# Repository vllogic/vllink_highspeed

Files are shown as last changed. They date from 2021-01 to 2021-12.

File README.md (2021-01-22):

# Vllink HighSpeed

## 简介

Vllink Highspeed是一款中低成本高性能调试器。相比Lite版，支持USB2.0高速、更好的IO时序优化、更好的CPU速度，预计JTAG/SWD接口对目标芯片SRAM速度可以达到MB/S的级别，媲美当前千元级别调试器。

## 硬件

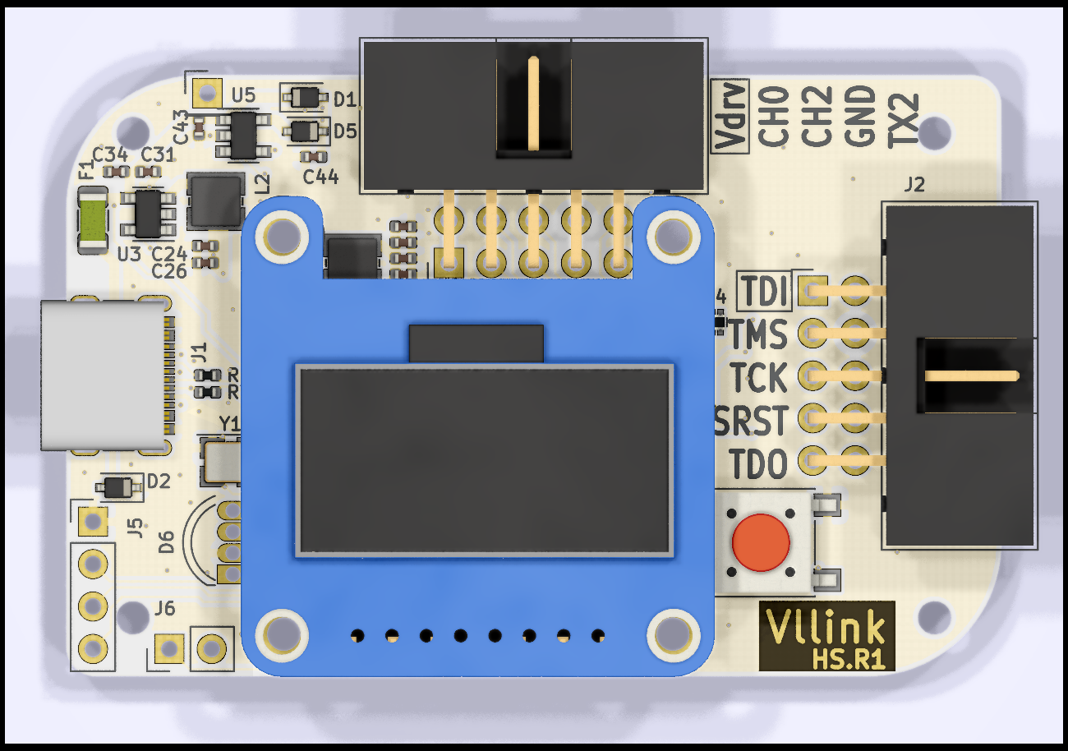
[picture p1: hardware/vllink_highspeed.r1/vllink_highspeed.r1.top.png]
top

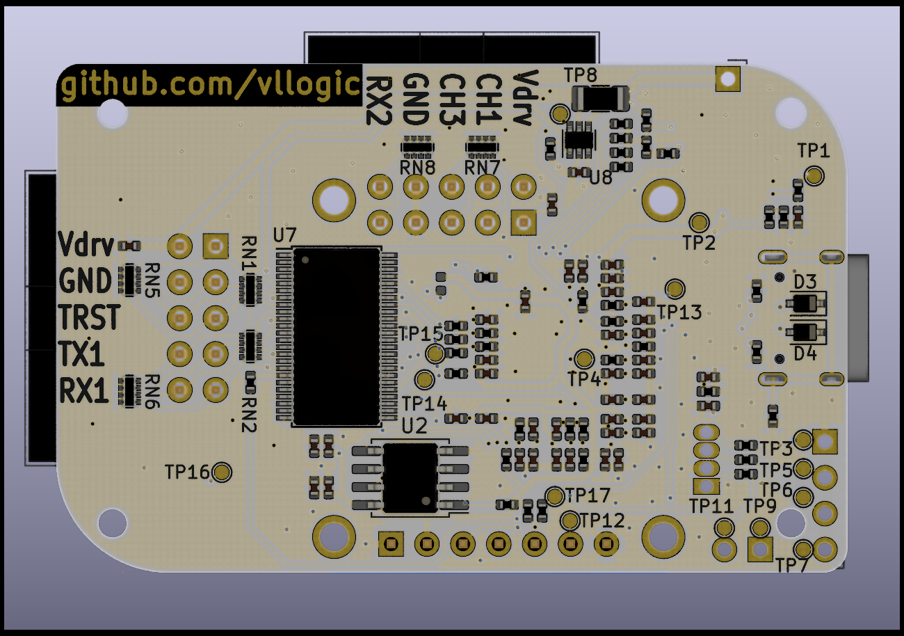
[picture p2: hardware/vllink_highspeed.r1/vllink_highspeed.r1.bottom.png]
bottom

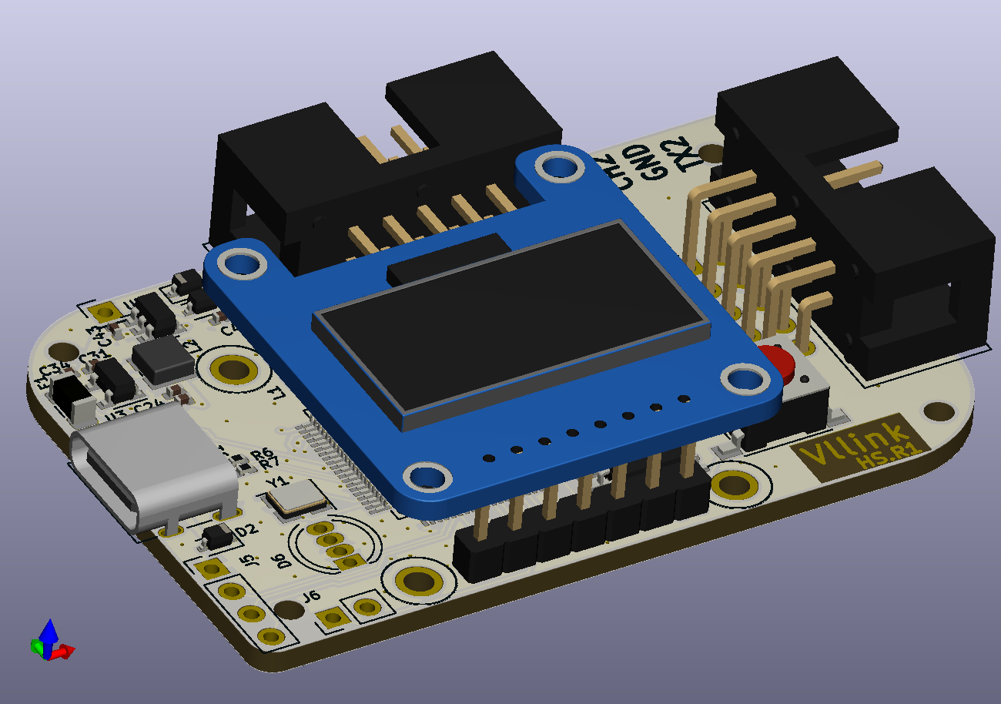
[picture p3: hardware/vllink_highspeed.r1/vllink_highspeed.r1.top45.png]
top45


## 功能
* JTAG/SWD接口(TDI,TMS,TCK,SRST,TDO,TRST)
* 2路独立串口(TX1,RX1,TX2,RX2)，1路共用串口(TDO,SRST)
* 4通道逻辑分析输入口(CH0,CH1,CH2,CH3)
* 具有电平转换电路，同时支持外部参考电源与内部数字可调电源1.5V至4.75V(Vdrv)
* 使用内部电源对外供电时，支持电流测量(Vdrv)
* OLED_12864(全彩LED可选)
* 远超同等价格级别硬件的Code/Data空间

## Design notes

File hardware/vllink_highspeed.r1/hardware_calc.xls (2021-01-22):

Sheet: LDO_OUT1
Vref | R1 | R2.1 | R2.1_X | R2.1_R | R2.2 | R2.2_X | R2.2_R | R2.3 | R2.3_X | R2.3_R | R2.4 | R2.4_X | R2.4_R | R2.5 | R2.5_X | R2.5_R | R2(12) | R2(34) | R2(1234) | R2(12345) | Vout
1.207 | 100 | 412 | 1 | 412 | 60.4 | 10000 | 604000 | 121 | 10000 | 1210000 | 243 | 10000 | 2430000 | 475 | 10000 | 4750000 | 411.7191585 | 807774.7253 | 411.509414 | 411.4737665 | 1.500335833
1.207 | 100 | 412 | 1 | 412 | 60.4 | 10000 | 604000 | 121 | 10000 | 1210000 | 243 | 10000 | 2430000 | 475 | 1 | 475 | 411.7191585 | 807774.7253 | 411.509414 | 220.4905764 | 1.754415685
1.207 | 100 | 412 | 1 | 412 | 60.4 | 10000 | 604000 | 121 | 10000 | 1210000 | 243 | 1 | 243 | 475 | 10000 | 4750000 | 411.7191585 | 242.951209 | 152.7908888 | 152.7859742 | 1.996993981
1.207 | 100 | 412 | 1 | 412 | 60.4 | 10000 | 604000 | 121 | 10000 | 1210000 | 243 | 1 | 243 | 475 | 1 | 475 | 411.7191585 | 242.951209 | 152.7908888 | 115.604851 | 2.251073834
1.207 | 100 | 412 | 1 | 412 | 60.4 | 10000 | 604000 | 121 | 1 | 121 | 243 | 10000 | 2430000 | 475 | 10000 | 4750000 | 411.7191585 | 120.9939752 | 93.51287682 | 93.51103587 | 2.497756742
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

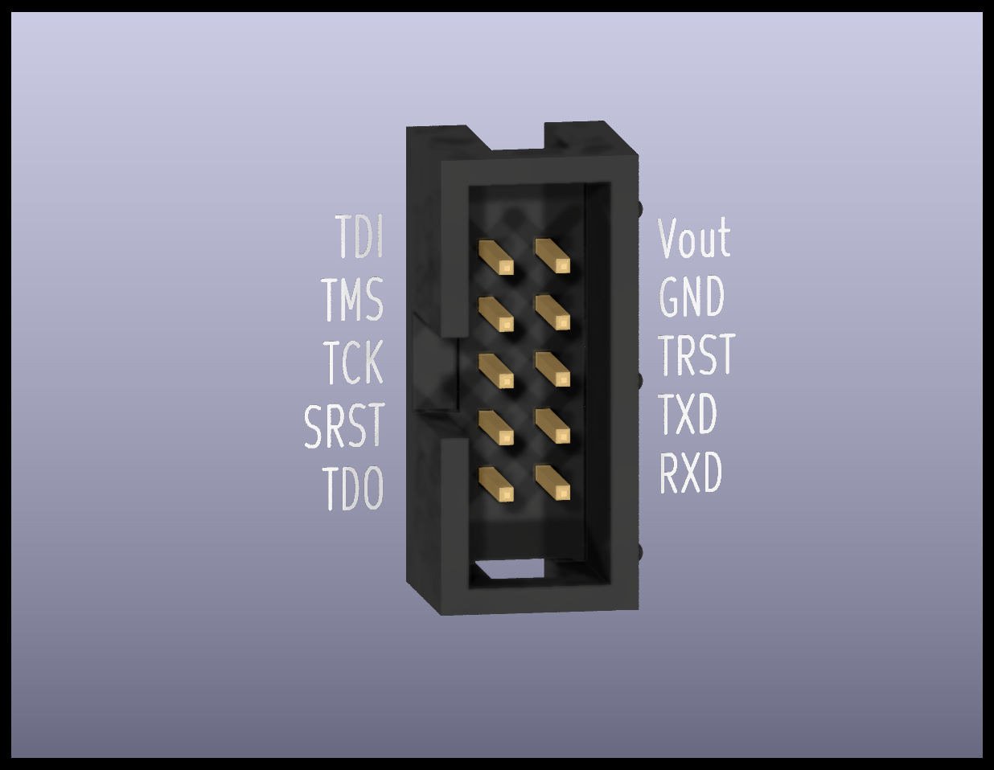
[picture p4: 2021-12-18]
hardware/vllink_basic/hardware.version1/vllink_basic.20211123.interface.png

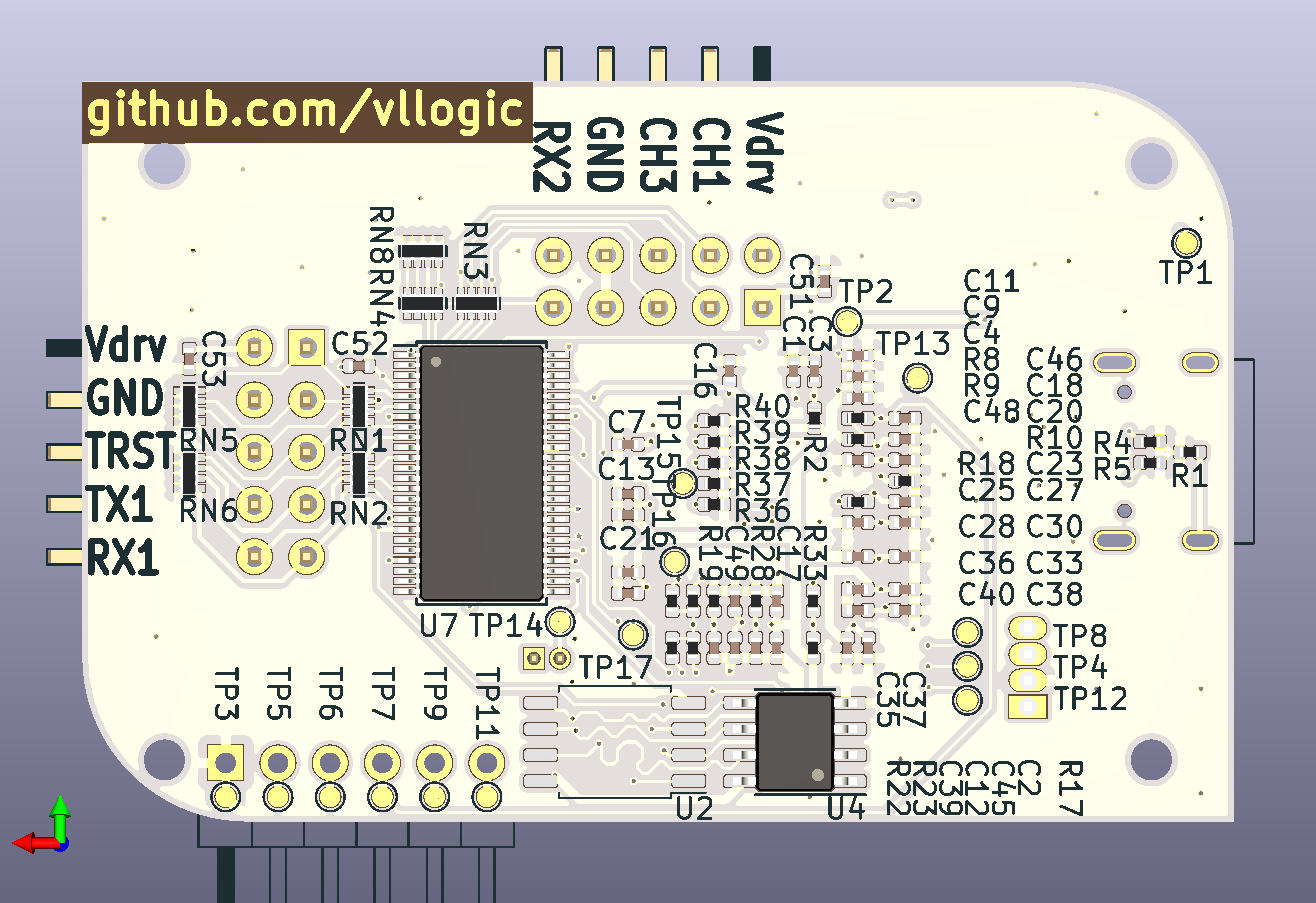
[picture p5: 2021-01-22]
hardware/vllink_highspeed.r0/vllink_highspeed.r0.bottom.png

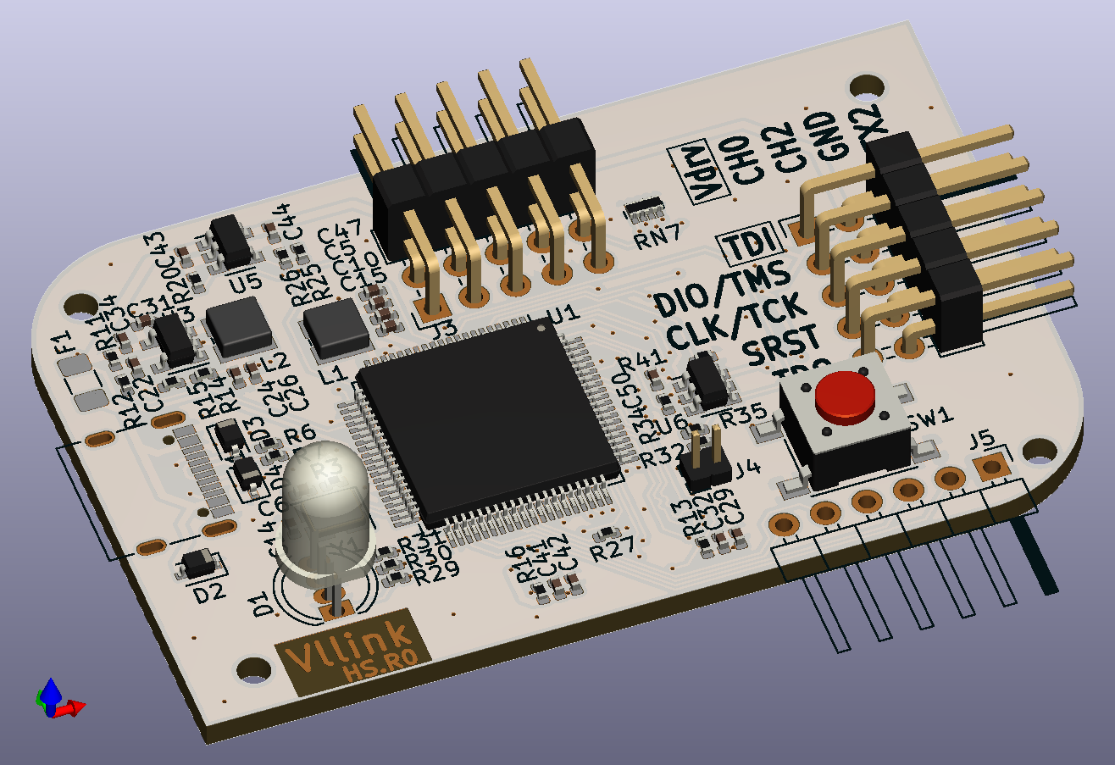
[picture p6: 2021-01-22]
hardware/vllink_highspeed.r0/vllink_highspeed.r0.top45.png

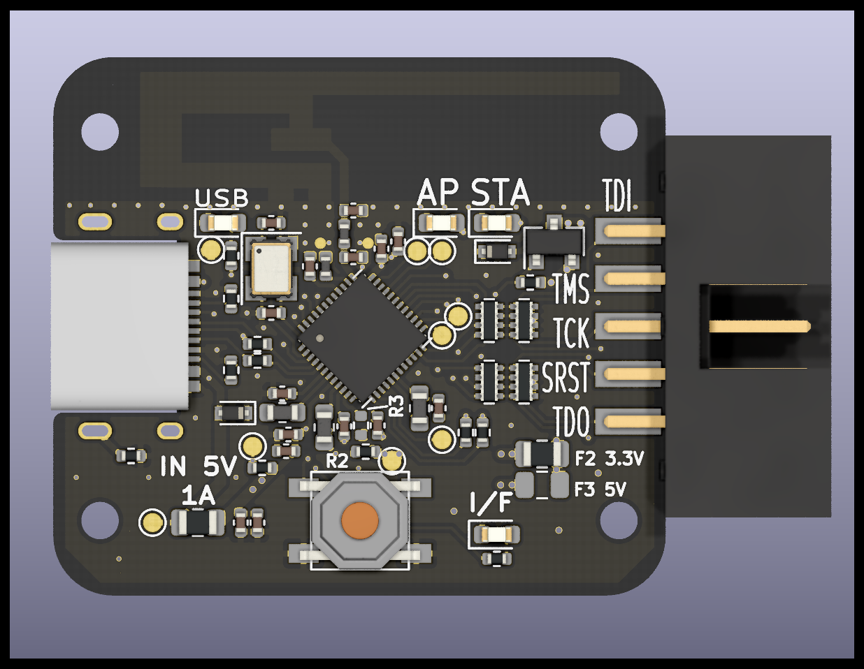
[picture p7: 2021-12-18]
hardware/vllink_basic/hardware.version1/vllink_basic.20211123.top.png

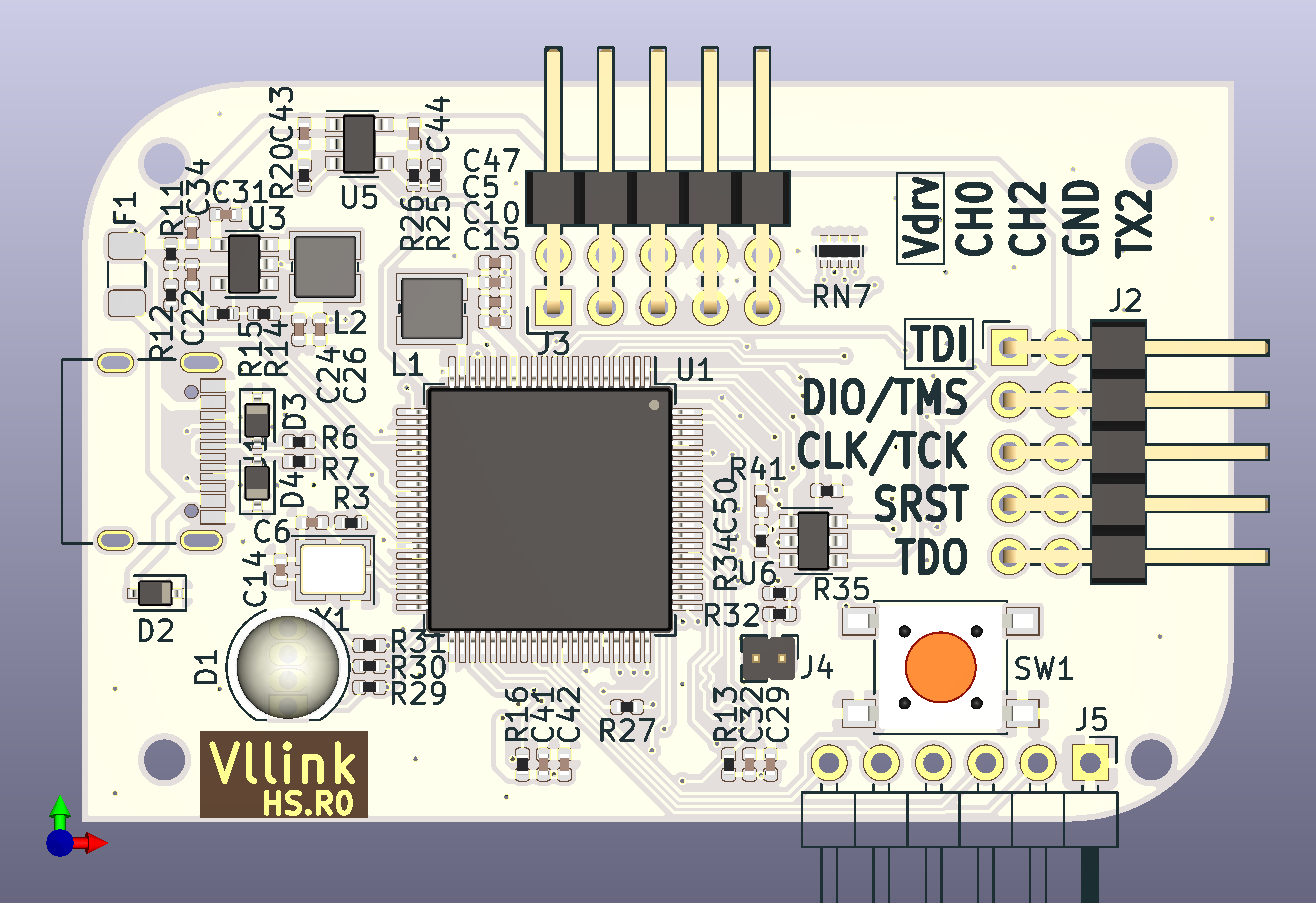
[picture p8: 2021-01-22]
hardware/vllink_highspeed.r0/vllink_highspeed.r0.top.png

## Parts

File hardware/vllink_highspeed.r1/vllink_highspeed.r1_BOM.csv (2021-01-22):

Comment | Description | Designator | Footprint | LibRef | Pins | Quantity | PartNumber | url
0.22uF | desc | C26,C15, | C_0402_1005Metric | libref | 2 | 2
10uF | desc | C43,C44,C47,C34,C24,C10,C5, | C_0402_1005Metric | libref | 2 | 7
0.1uF | desc | C52,C50,C31, | C_0402_1005Metric | libref | 2 | 3
BAT60A, NC | desc | D1, | D_SOD-323 | libref | 2 | 1
LESD3Z5.0C | desc | D2, | D_SOD-323 | libref | 2 | 1
BAT60A | desc | D5, | D_SOD-323 | libref | 2 | 1
Polyfuse,2A | desc | F1, | Fuse_1206_3216Metric | libref | 2 | 1
4.7uH | desc | L1,L2, | L_Wuerth_MAPI-3012 | libref | 2 | 2
4.7k | desc | R32, | R_0402_1005Metric | libref | 2 | 1
22 | desc | R7,R6, | R_0402_1005Metric | libref | 2 | 2
220 | desc | RN4,RN3, | R_Array_Concave_4x0402 | libref | 8 | 2
SW_Push | desc | SW1, | SW_SPST_PTS645 | libref | 4 | 1
MIMXRT1011 | desc | U1, | LQFP-80_12x12mm_P0.5mm | libref | 80 | 1
ETA3486 | desc | U3, | SOT-23-5 | libref | 5 | 1
W25Q128JVS | desc | U4, | SOIC-8_P1.27mm_Common | libref | 8 | 1
SGM2019-ADJ | desc | U5, | SOT-23-5 | libref | 5 | 1
74LVC1T45GW | desc | U6, | SOT-363_SC-70-6 | libref | 6 | 1
24M, 12pF | desc | Y1, | Crystal_SMD_3225-4Pin_3.2x2.5mm | libref | 4 | 1
12pF | desc | C14,C6, | C_0402_1005Metric | libref | 2 | 2
0.22uF | desc | C38,C35,C33,C30,C22,C20,C18,C12,C11,C7,C4,C3,C1, | C_0402_1005Metric | libref | 2 | 13
1uF | desc | C42,C37,C32,C23, | C_0402_1005Metric | libref | 2 | 4
4.7uF | desc | C49,C48,C40,C36,C28,C21,C19,C17,C9, | C_0402_1005Metric | libref | 2 | 9
10uF | desc | C53,C51,C25, | C_0402_1005Metric | libref | 2 | 3
0.1uF | desc | C54,C46,C41,C45,C39,C29,C27,C16,C13,C8,C2, | C_0402_1005Metric | libref | 2 | 11
LESD3Z5.0C | desc | D4,D3, | D_SOD-323 | libref | 2 | 2
0,NC | desc | R12, | R_0402_1005Metric | libref | 2 | 1
47k | desc | R13,R30,R41,R40,R39,R38,R37,R36,R35,R16,R20,R33, | R_0402_1005Metric | libref | 2 | 12
274k,1% | desc | R14, | R_0402_1005Metric | libref | 2 | 1
30k | desc | R2, | R_0402_1005Metric | libref | 2 | 1
121k,1% | desc | R22, | R_0402_1005Metric | libref | 2 | 1
243k,1% | desc | R23, | R_0402_1005Metric | libref | 2 | 1
475k,1% | desc | R24, | R_0402_1005Metric | libref | 2 | 1
100k,1% | desc | R25,R11, | R_0402_1005Metric | libref | 2 | 2
412k,1% | desc | R26, | R_0402_1005Metric | libref | 2 | 1
60.4k,1% | desc | R28,R27,R21,R19,R18,R15, | R_0402_1005Metric | libref | 2 | 6
0.05, 1%, 1206 | desc | R29, | R_1206_3216Metric | libref | 2 | 1
2.2M | desc | R3, | R_0402_1005Metric | libref | 2 | 1
47k,NC | desc | R34,R17, | R_0402_1005Metric | libref | 2 | 2
4.7k | desc | R43,R42,R31, | R_0402_1005Metric | libref | 2 | 3
0 | desc | R44,R10,R9,R1, | R_0402_1005Metric | libref | 2 | 4
5.1k | desc | R5,R4, | R_0402_1005Metric | libref | 2 | 2
10k | desc | R8, | R_0402_1005Metric | libref | 2 | 1
220 | desc | RN2,RN1, | R_Array_Concave_4x0402 | libref | 8 | 2
220k | desc | RN8,RN7,RN6,RN5, | R_Array_Concave_4x0402 | libref | 8 | 4
TestPoint | desc | TP17,TP16,TP15,TP13,TP12,TP11,TP9,TP8,TP7,TP6,TP5,TP4,TP3,TP2,TP1,TP14, | TestPoint_Pad_D1.0mm | libref | 1 | 16
LY68L6400 | desc | U2, | SOIC-8_P1.27mm_Common | libref | 8 | 1
74ALVC164245DGG | desc | U7, | TSSOP-48_6.1x12.5mm_P0.5mm | libref | 48 | 1
TP199A2/TP181A2 | desc | U8, | SOT-363_SC-70-6 | libref | 6 | 1
Through Hole Items
LED_RCGB | desc | D6, | LED_D5.0mm-4_RGB | libref | 4 | 1
USB_C_Receptacle_USB2.0 | desc | J1, | USB_C_Receptacle_Palconn_UTC16-G | libref | 22 | 1
JTAG/SWD/UART0 | desc | J2, | IDC-Header_2x05_P2.54mm_Horizontal | libref | 10 | 1
LogicIN/UART1 | desc | J3, | IDC-Header_2x05_P2.54mm_Horizontal | libref | 10 | 1
Mode | desc | J4, | PinHeader_1x02_P1.27mm_Vertical | libref | 2 | 1
SWD | desc | J5, | PinHeader_1x04_P2.54mm_Vertical | libref | 4 | 1
UART | desc | J6, | PinHeader_1x02_P2.54mm_Vertical | libref | 2 | 1
Vdrive_I | desc | J7, | PinHeader_1x01_P2.54mm_Vertical | libref | 1 | 1
OLED_12864 | desc | OLED1, | OLED_12864 | libref | 11 | 1

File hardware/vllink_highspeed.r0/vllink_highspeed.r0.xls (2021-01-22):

Reference | Quantity | Value | Footprint | 单价 | 合计
C28 C40 C9 C36 C19 C21 C17 C49 C48 | 9 | 4.7uF | Capacitor_SMD:C_0402_1005Metric | 0.01 | 0.09
C35 C20 C30 C38 C3 C4 C11 C33 C26 C22 C15 C1 C7 C12 C18 | 15 | 0.22uF | Capacitor_SMD:C_0402_1005Metric | 0.01 | 0.15
C37 C23 C32 C42 | 4 | 1uF | Capacitor_SMD:C_0402_1005Metric | 0.01 | 0.04
C43 C44 C25 C34 C24 C5 C10 C47 C51 C53 | 10 | 10uF | Capacitor_SMD:C_0402_1005Metric | 0.01 | 0.1
C45 C39 C27 C29 C31 C8 C2 C13 C16 C46 C41 C50 C52 | 13 | 0.1uF | Capacitor_SMD:C_0402_1005Metric | 0.01 | 0.13
C6 C14 | 2 | 12pF | Capacitor_SMD:C_0402_1005Metric | 0.01 | 0.02
D1 | 1 | LED_RCGB | LED_THT:LED_D5.0mm-4_RGB | 0 | 0
D2 D3 D4 | 3 | LESD3Z5.0C | Diode_SMD:D_SOD-323 | 0.1 | 0.3
F1 | 1 | Polyfuse,2A | Fuse:Fuse_1206_3216Metric | 0.16 | 0.16
J1 | 1 | USB_C_Receptacle_USB2.0 | Connector_USB:USB_C_Receptacle_Palconn_UTC16-G | 0.4 | 0.4
J2 | 1 | JTAG/SWD/UART0 | Connector_PinHeader_2.54mm:PinHeader_2x05_P2.54mm_Horizontal | 0.3 | 0.3
J3 | 1 | LogicIN/UART1 | Connector_PinHeader_2.54mm:PinHeader_2x05_P2.54mm_Horizontal | 0.3 | 0.3
J4 | 1 | NC | Connector_PinHeader_1.27mm:PinHeader_1x02_P1.27mm_Vertical | 0 | 0
J5 | 1 | Debug | Connector_PinHeader_2.54mm:PinHeader_1x06_P2.54mm_Horizontal | 0 | 0
L2 L1 | 2 | 4.7uH | Inductor_SMD:L_Wuerth_MAPI-3012 | 0.2 | 0.4
R1 R9 R10 | 3 | 0 | Resistor_SMD:R_0402_1005Metric | 0.01 | 0.03
R12 R17 | 2 | 10k,NC | Resistor_SMD:R_0402_1005Metric | 0.01 | 0.02
R13 R16 R35 R41 R36 R37 R38 R39 R40 | 9 | 47k | Resistor_SMD:R_0402_1005Metric | 0.01 | 0.09
R14 | 1 | 274k,1% | Resistor_SMD:R_0402_1005Metric | 0.01 | 0.01
R2 | 1 | 30k | Resistor_SMD:R_0402_1005Metric | 0.01 | 0.01
R20 R33 R8 | 3 | 10k | Resistor_SMD:R_0402_1005Metric | 0.01 | 0.03
R21 R27 R28 R18 R19 R15 | 6 | 60.4k,1% | Resistor_SMD:R_0402_1005Metric | 0.01 | 0.06
R22 | 1 | 121k,1% | Resistor_SMD:R_0402_1005Metric | 0.01 | 0.01
R23 | 1 | 243k,1% | Resistor_SMD:R_0402_1005Metric | 0.01 | 0.01
R25 R11 | 2 | 100k,1% | Resistor_SMD:R_0402_1005Metric | 0.01 | 0.02
R26 R24 | 2 | 412k,1% | Resistor_SMD:R_0402_1005Metric | 0.01 | 0.02
R29 R30 R31 R32 | 4 | 4.7k | Resistor_SMD:R_0402_1005Metric | 0.01 | 0.04
R3 | 1 | 2.2M | Resistor_SMD:R_0402_1005Metric | 0.01 | 0.01
R34 | 1 | 47k,NC | Resistor_SMD:R_0402_1005Metric | 0.01 | 0.01
R4 R5 | 2 | 5.1k | Resistor_SMD:R_0402_1005Metric | 0.01 | 0.02
R7 R6 | 2 | 22 | Resistor_SMD:R_0402_1005Metric | 0.01 | 0.02
RN1 RN2 RN3 RN4 | 4 | 220 | Resistor_SMD:R_Array_Concave_4x0402 | 0.08 | 0.32
RN5 RN6 RN8 RN7 | 4 | 220k | Resistor_SMD:R_Array_Concave_4x0402 | 0.08 | 0.32
SW1 | 1 | SW_Push | Button_Switch_SMD:SW_SPST_PTS645 | 0.08 | 0.08
TP1 TP2 TP3 TP4 TP5 TP6 TP8 TP11 TP9 TP7 TP13 TP14 TP15 TP16 TP17 TP12 | 16 | TestPoint | TestPoint:TestPoint_Pad_D1.0mm | 0 | 0
U1 | 1 | MIMXRT1011 | Package_QFP:LQFP-80_12x12mm_P0.5mm | 10 | 10
U2 | 1 | W25Q128JVS | Package_SO:SOIC-8_5.23x5.23mm_P1.27mm | 1.5 | 1.5
U3 | 1 | ETA3486 | Package_TO_SOT_SMD:SOT-23-5 | 0.3 | 0.3
U4 | 1 | PSRAM, NC | Package_SO:SOIC-8_3.9x4.9mm_P1.27mm | 3.3 | 3.3
U5 | 1 | SGM2019-ADJ | Package_TO_SOT_SMD:SOT-23-5 | 0.2 | 0.2
U6 | 1 | 74LVC1T45GW | Package_TO_SOT_SMD:SOT-23-6 | 1.2 | 1.2
U7 | 1 | 74ALVC164245DGG | Package_SO:TSSOP-48_6.1x12.5mm_P0.5mm | 2.4 | 2.4
Y1 | 1 | 24M, 12pF | Crystal:Crystal_SMD_3225-4Pin_3.2x2.5mm | 0.3 | 0.3
外壳 | 1 |  |  | 3 | 3
USB线材 | 1 |  |  | 2 | 2
生产测试包装 | 1 |  |  | 7 | 7
 | 139 |  |  |  | 34.72

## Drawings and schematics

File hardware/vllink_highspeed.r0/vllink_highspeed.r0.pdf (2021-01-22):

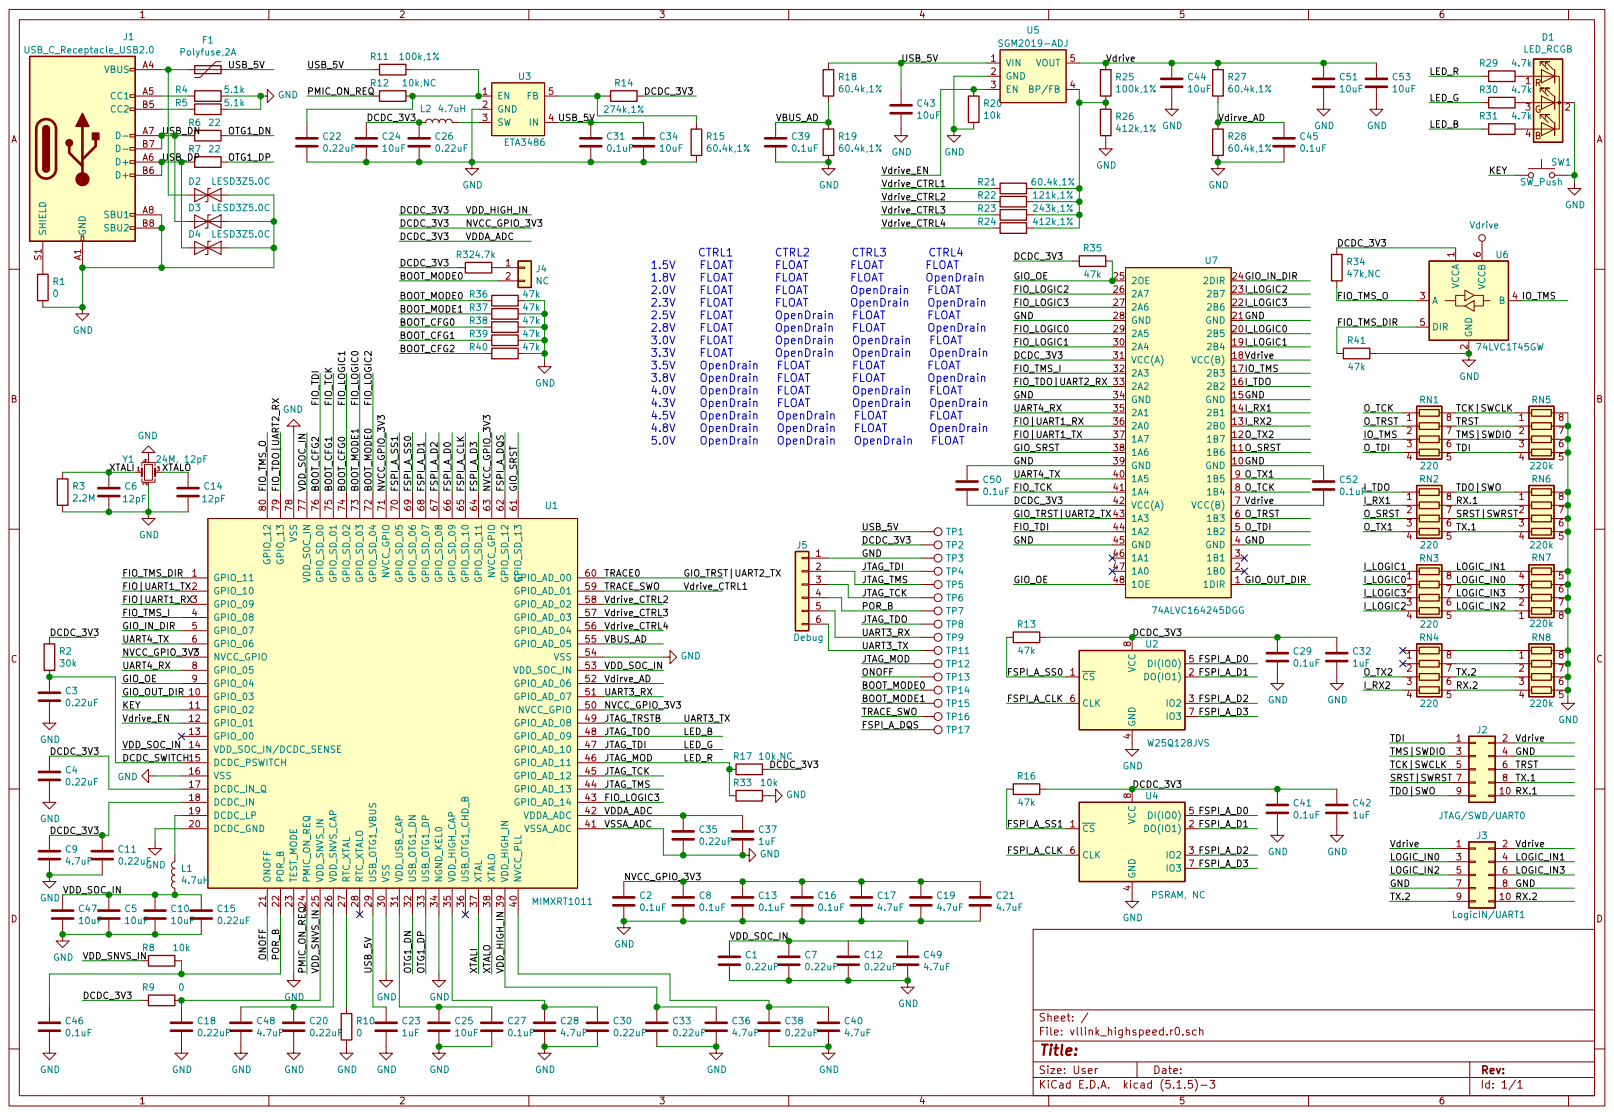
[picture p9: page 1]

Vdrive Vdrive GND GND GND GND GIO_OUT_DIR
I_LOGIC1

5.0V OpenDrain OpenDrain OpenDrain FLOAT

7 2 | 7
6 3 | 6

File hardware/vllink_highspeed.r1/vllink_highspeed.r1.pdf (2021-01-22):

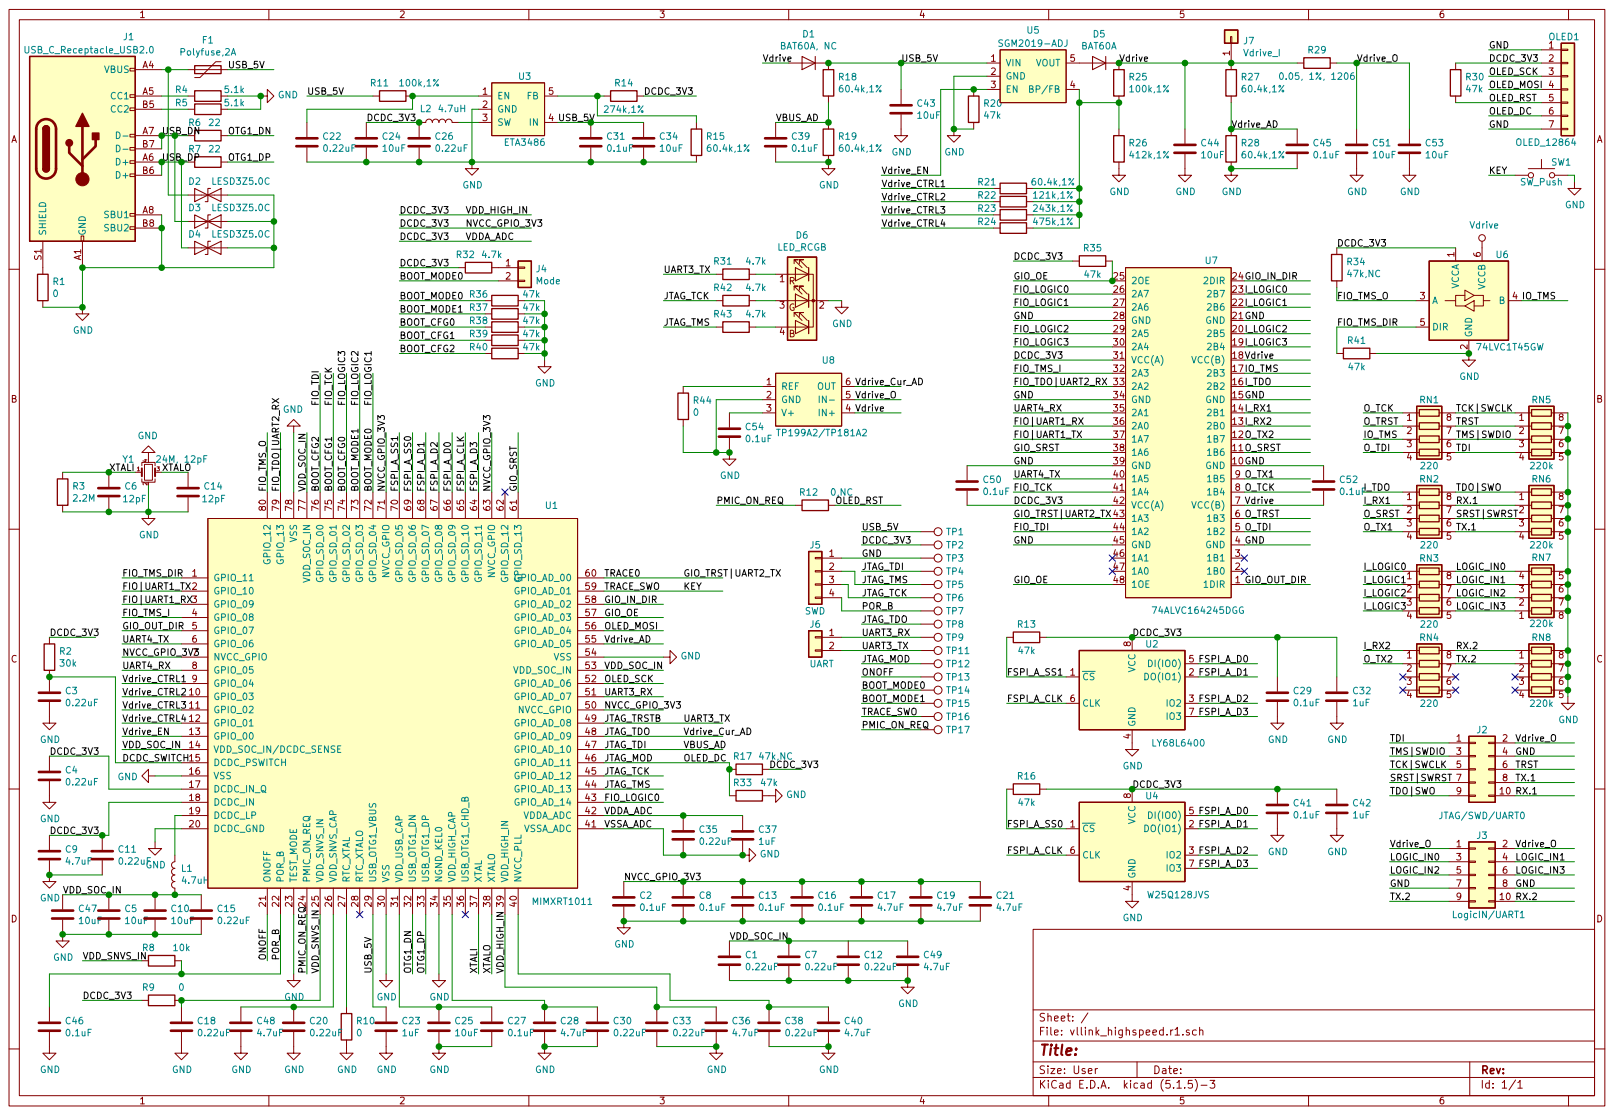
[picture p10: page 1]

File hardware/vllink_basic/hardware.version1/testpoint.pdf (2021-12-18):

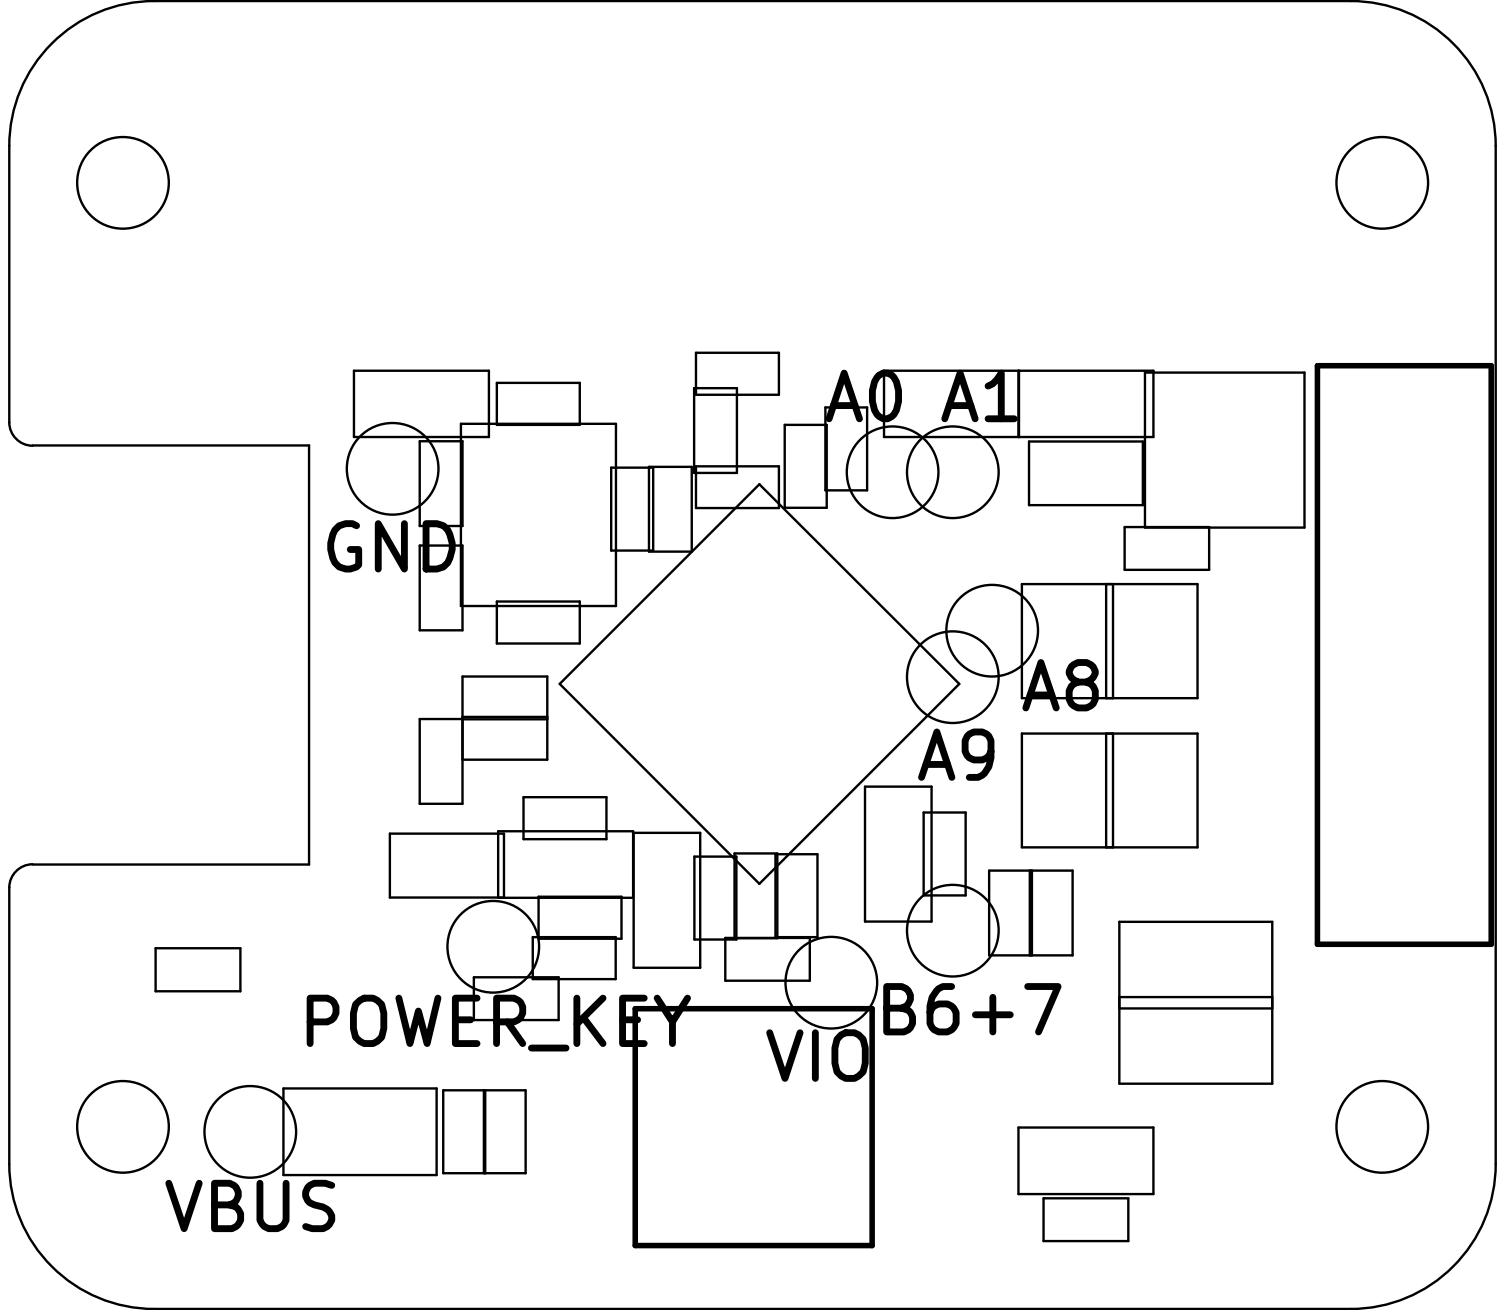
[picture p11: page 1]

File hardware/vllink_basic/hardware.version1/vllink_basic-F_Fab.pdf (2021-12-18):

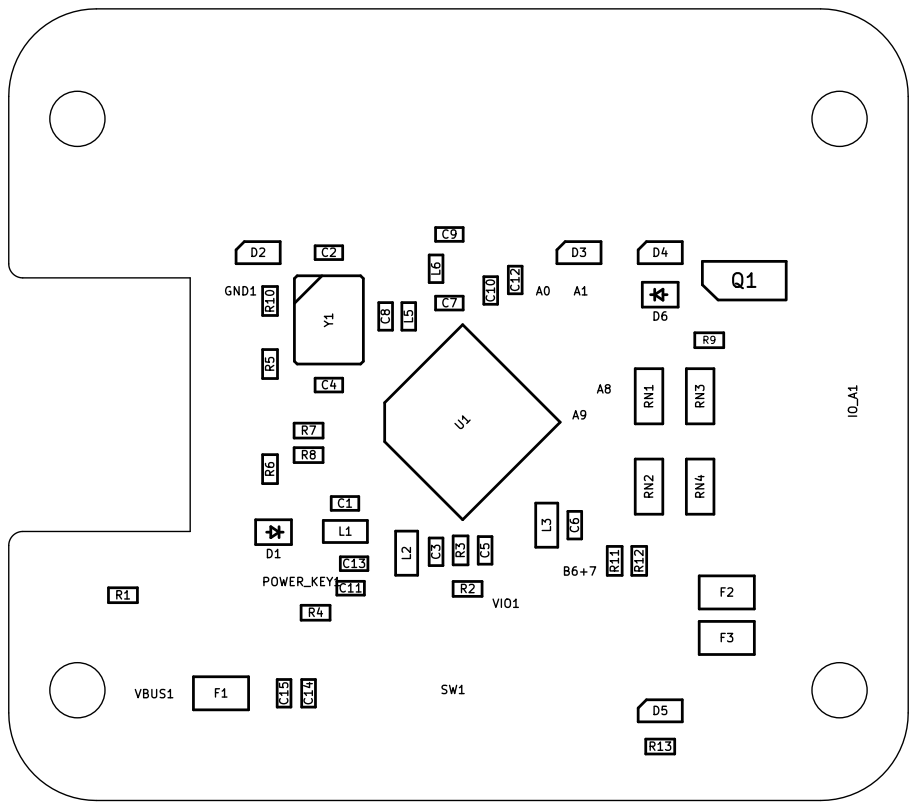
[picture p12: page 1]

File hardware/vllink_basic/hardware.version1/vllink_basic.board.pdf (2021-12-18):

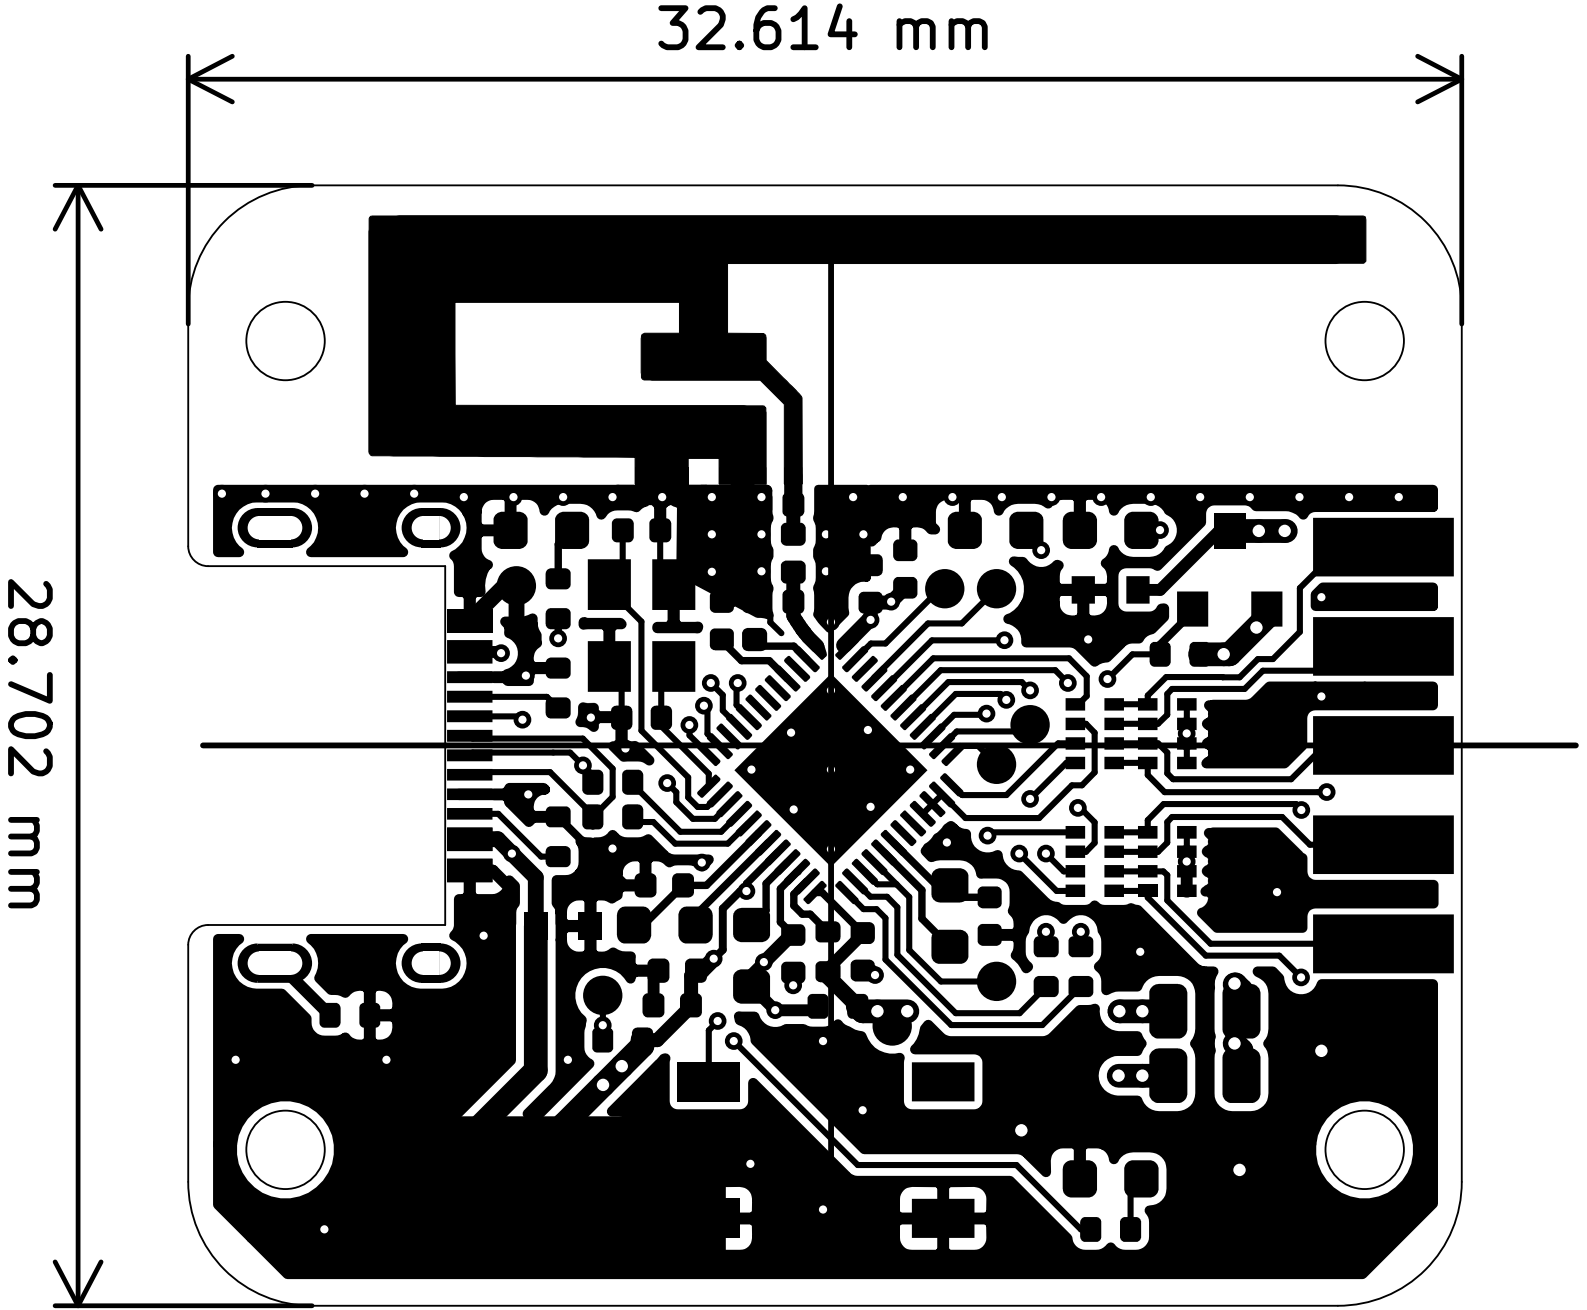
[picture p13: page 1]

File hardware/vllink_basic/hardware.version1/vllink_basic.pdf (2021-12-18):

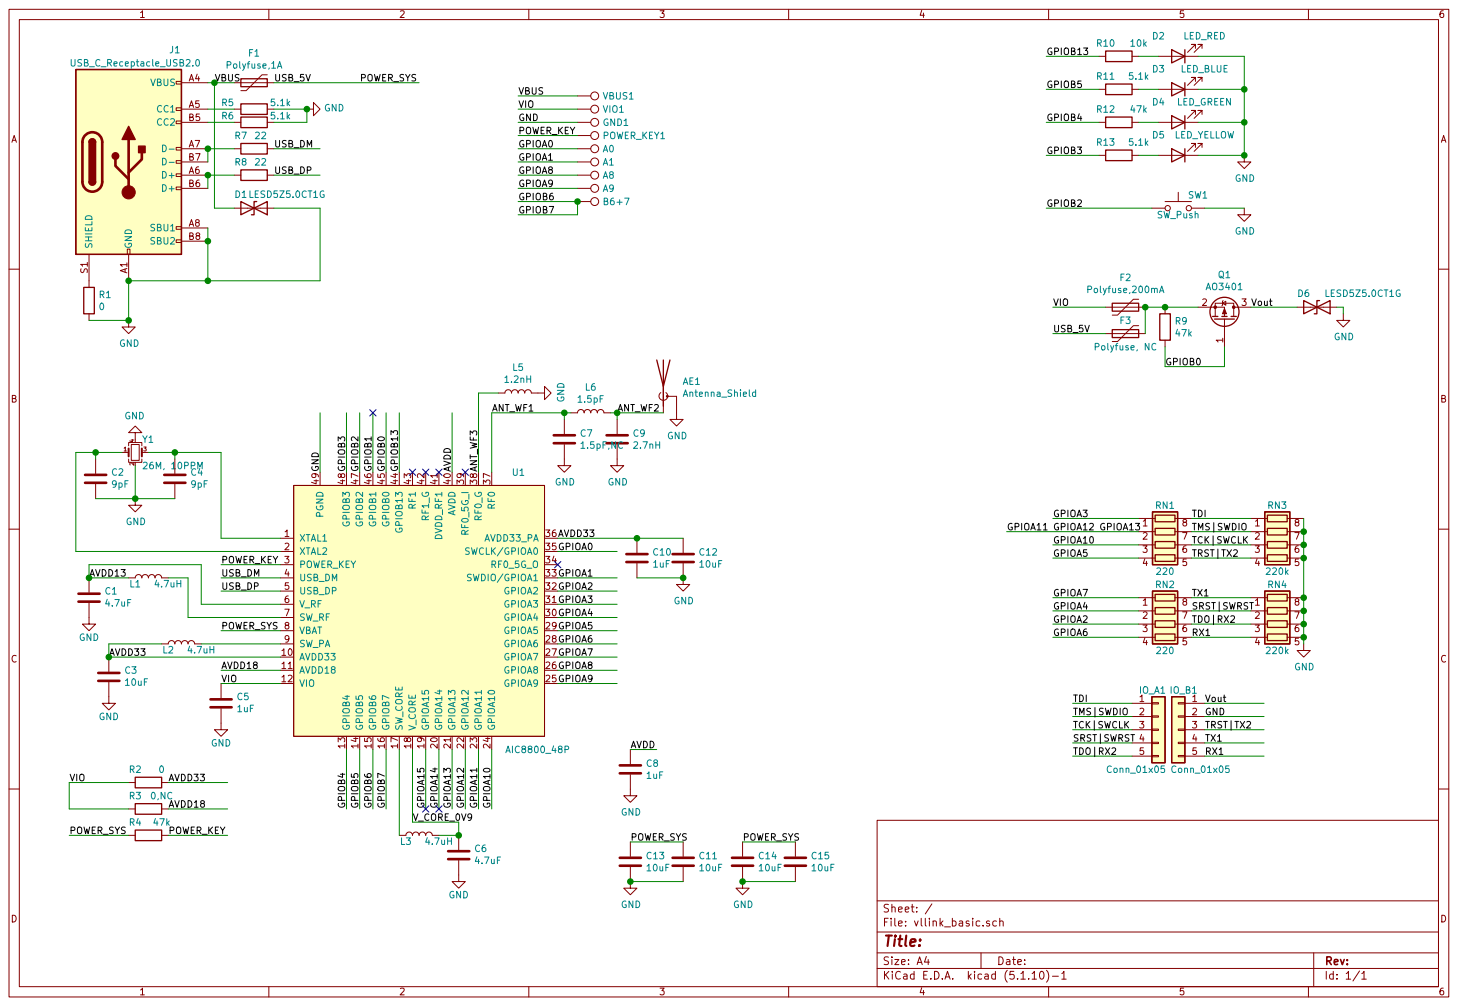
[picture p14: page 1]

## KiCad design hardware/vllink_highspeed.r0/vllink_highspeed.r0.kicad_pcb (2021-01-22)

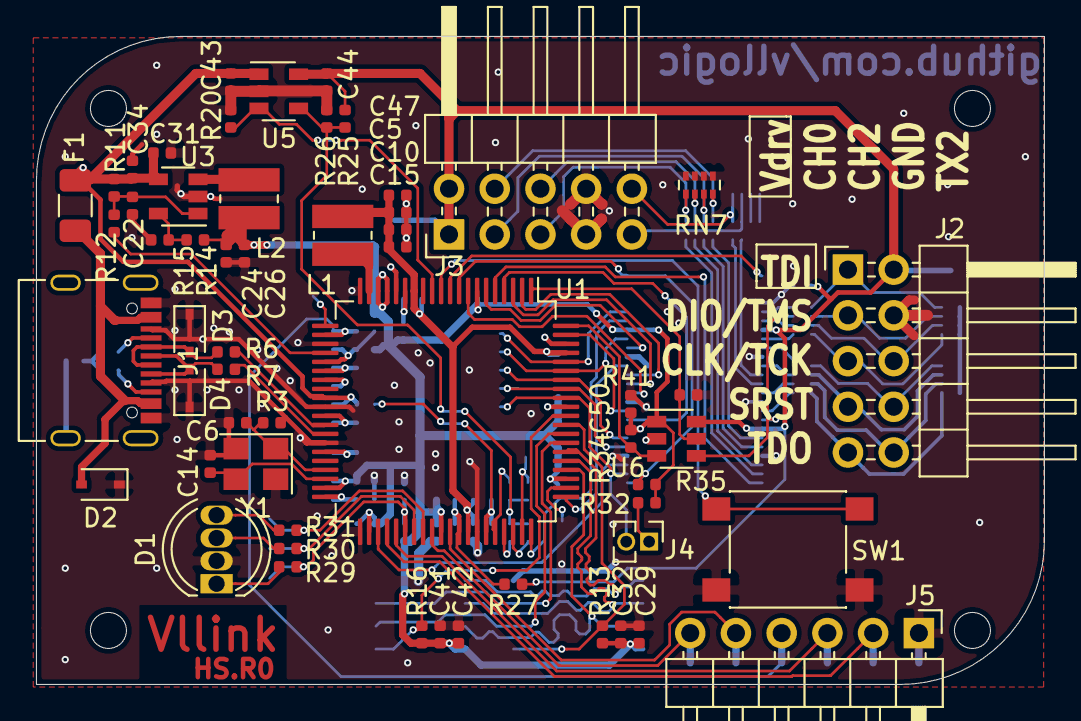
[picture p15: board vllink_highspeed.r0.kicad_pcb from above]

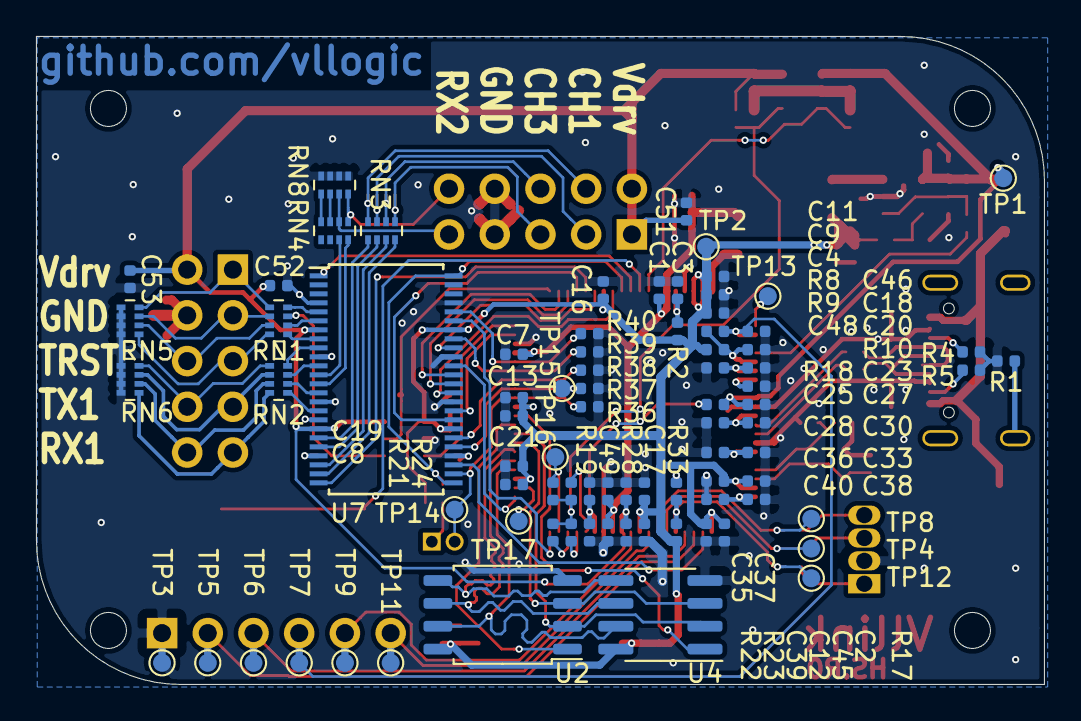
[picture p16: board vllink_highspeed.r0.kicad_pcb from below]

Board: 2 copper layers, 56.0 x 36.0 mm, 139 parts (82 on the bottom side), 106 nets.

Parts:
C1, C3, C4, C7, C11, C12, C15, C18, C20, C22, C26, C30, C33, C35, C38: 0.22uF; C_0402_1005Metric
C2, C8, C13, C16, C27, C29, C31, C39, C41, C45, C46, C50, C52: 0.1uF; C_0402_1005Metric
C5, C10, C24, C25, C34, C43, C44, C47, C51, C53: 10uF; C_0402_1005Metric
C6, C14: 12pF; C_0402_1005Metric
C9, C17, C19, C21, C28, C36, C40, C48, C49: 4.7uF; C_0402_1005Metric
C23, C32, C37, C42: 1uF; C_0402_1005Metric
D1: LED_RCGB; LED_D5.0mm-4_RGB
D2, D3, D4: LESD3Z5.0C; D_SOD-323
F1: Polyfuse,2A; Fuse_1206_3216Metric
J1: USB_C_Receptacle_USB2.0; USB_C_Receptacle_Palconn_UTC16-G
J2: JTAG/SWD/UART0; PinHeader_2x05_P2.54mm_Horizontal
J3: LogicIN/UART1; PinHeader_2x05_P2.54mm_Horizontal
J4: NC; PinHeader_1x02_P1.27mm_Vertical
J5: Debug; PinHeader_1x06_P2.54mm_Horizontal
L1, L2: 4.7uH; L_Wuerth_MAPI-3012
R1, R9, R10: 0; R_0402_1005Metric
R2: 30k; R_0402_1005Metric
R3: 2.2M; R_0402_1005Metric
R4, R5: 5.1k; R_0402_1005Metric
R6, R7: 22; R_0402_1005Metric
R8, R20, R33: 10k; R_0402_1005Metric
R11, R25: 100k,1%; R_0402_1005Metric
R12, R17: 10k,NC; R_0402_1005Metric
R13, R16, R35, R36, R37, R38, R39, R40, R41: 47k; R_0402_1005Metric
R14: 274k,1%; R_0402_1005Metric
R15, R18, R19, R21, R27, R28: 60.4k,1%; R_0402_1005Metric
R22: 121k,1%; R_0402_1005Metric
R23: 243k,1%; R_0402_1005Metric
R24, R26: 412k,1%; R_0402_1005Metric
R29, R30, R31, R32: 4.7k; R_0402_1005Metric
R34: 47k,NC; R_0402_1005Metric
RN1, RN2, RN3, RN4: 220; R_Array_Concave_4x0402
RN5, RN6, RN7, RN8: 220k; R_Array_Concave_4x0402
SW1: SW_Push; SW_SPST_PTS645
TP1, TP2, TP3, TP4, TP5, TP6, TP7, TP8, TP9, TP11, TP12, TP13, TP14, TP15, TP16, TP17: TestPoint; TestPoint_Pad_D1.0mm
U1: MIMXRT1011; LQFP-80_12x12mm_P0.5mm
U2: W25Q128JVS; SOIC-8_5.23x5.23mm_P1.27mm
U3: ETA3486; SOT-23-5
U4: PSRAM, NC; SOIC-8_3.9x4.9mm_P1.27mm
U5: SGM2019-ADJ; SOT-23-5
U6: 74LVC1T45GW; SOT-23-6
U7: 74ALVC164245DGG; TSSOP-48_6.1x12.5mm_P0.5mm
Y1: 24M, 12pF; Crystal_SMD_3225-4Pin_3.2x2.5mm

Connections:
/BOOT_CFG0: R38.2, U1.74, U7.30
/BOOT_CFG1: R39.2, U1.75, U7.41
/BOOT_CFG2: R40.2, U1.76, U7.44
/BOOT_MODE0: J4.2, R36.2, TP14.1, U1.72, U7.26
/BOOT_MODE1: R37.2, TP15.1, U1.73, U7.29
/DCDC_3V3: C2.1, C4.1, C8.1, C9.1, C11.1, C13.1, C16.1, C17.1, C19.1, C21.1, C24.1, C26.1, C29.1, C32.1, C33.1, C35.1, C36.1, C37.1, C41.1, C42.1, C50.2, L2.1, R2.1, R9.2, R13.1, R14.1, R16.1, R17.1, R32.2, R34.1, R35.2, TP2.1, U1.7, U1.17, U1.18, U1.39, U1.42, U1.50, U1.63, U1.71, U2.8, U4.8, U6.1, U7.31, U7.42
/DCDC_SWITCH: C3.1, R2.2, U1.15
/FIO_LOGIC3: U1.43, U7.27
/FIO_TDO|UART2_RX: U1.79, U7.33
/FIO_TMS_DIR: R41.2, U1.1, U6.5
/FIO_TMS_I: U1.4, U7.32
/FIO_TMS_O: R34.2, U1.80, U6.3
/FIO|UART1_RX: U1.3, U7.36
/FIO|UART1_TX: U1.2, U7.37
/FSPI_A_CLK: U1.65, U2.6, U4.6
/FSPI_A_D0: U1.66, U2.5, U4.5
/FSPI_A_D1: U1.68, U2.2, U4.2
/FSPI_A_D2: U1.67, U2.3, U4.3
/FSPI_A_D3: U1.64, U2.7, U4.7
/FSPI_A_DQS: TP17.1, U1.62
/FSPI_A_SS0: R13.2, U1.69, U2.1
/FSPI_A_SS1: R16.2, U1.70, U4.1
/GIO_IN_DIR: U1.5, U7.24
/GIO_OE: R35.1, U1.9, U7.25, U7.48
/GIO_OUT_DIR: U1.10, U7.1
/GIO_SRST: U1.61, U7.38
/GIO_TRST|UART2_TX: U1.60, U7.43
/IO_TMS: RN1.3, U6.4, U7.17
/I_LOGIC0: RN3.2, U7.20
/I_LOGIC1: RN3.1, U7.19
/I_LOGIC2: RN3.4, U7.23
/I_LOGIC3: RN3.3, U7.22
/I_RX1: RN2.2, U7.14
/I_RX2: RN4.4, U7.13
/I_TDO: RN2.1, U7.16
/JTAG_MOD: R17.2, R29.2, R33.2, TP12.1, U1.46
/JTAG_TCK: J5.3, TP6.1, U1.45
/JTAG_TDI: R30.2, TP4.1, U1.47
/JTAG_TDO: R31.2, TP8.1, U1.48
/JTAG_TMS: J5.2, TP5.1, U1.44
/JTAG_TRSTB: J5.6, TP11.1, U1.49
/KEY: SW1.1, U1.11
/LOGIC_IN0: J3.3, RN3.7, RN7.3
/LOGIC_IN1: J3.4, RN3.8, RN7.4
/LOGIC_IN2: J3.5, RN3.5, RN7.1
/LOGIC_IN3: J3.6, RN3.6, RN7.2
/ONOFF: TP13.1, U1.21
/OTG1_DN: R6.1, U1.32
/OTG1_DP: R7.1, U1.33
/O_SRST: RN2.3, U7.11
/O_TCK: RN1.1, U7.8
/O_TDI: RN1.4, U7.5
/O_TRST: RN1.2, U7.6
/O_TX1: RN2.4, U7.9
/O_TX2: RN4.3, U7.12
/PMIC_ON_REQ: R12.2, U1.24
/POR_B: C46.1, J5.4, R8.1, TP7.1, U1.22
/RX.1: J2.10, RN2.7, RN6.2
/RX.2: J3.10, RN4.5, RN8.4
/SRST|SWRST: J2.7, RN2.6, RN6.3
/TCK|SWCLK: J2.5, RN1.8, RN5.1
/TDI: J2.1, RN1.5, RN5.4
/TDO|SWO: J2.9, RN2.8, RN6.1
/TMS|SWDIO: J2.3, RN1.6, RN5.3
/TRACE_SWO: R21.2, TP16.1, U1.59
/TRST: J2.6, RN1.7, RN5.2
/TX.1: J2.8, RN2.5, RN6.4
/TX.2: J3.9, RN4.6, RN8.3
/UART3_RX: J5.5, TP9.1, U1.51
/UART4_RX: U1.8, U7.35
/UART4_TX: U1.6, U7.40
/USB_5V: C23.1, C31.1, C34.1, C43.1, F1.1, R11.2, R18.1, TP1.1, U1.29, U3.4, U5.1
/USB_DN: D3.2, J1.A7, J1.B7, R6.2
/USB_DP: D4.2, J1.A6, J1.B6, R7.2
/VBUS_AD: C39.1, R18.2, R19.1, U1.55
/VDD_SNVS_IN: C18.1, R8.2, R9.1, U1.25
/VDD_SOC_IN: C1.1, C5.1, C7.1, C10.1, C12.1, C15.1, C47.1, C49.1, L1.1, U1.14, U1.53, U1.77
/Vdirve_AD: C45.1, R27.2, R28.1, U1.52
/Vdrive_CTRL2: R22.2, U1.58
/Vdrive_CTRL3: R23.2, U1.57
/Vdrive_CTRL4: R24.2, U1.56
/Vdrive_EN: R20.1, U1.12, U5.3
/XTALI: C6.1, R3.1, U1.37, Y1.1
/XTALO: C14.1, U1.38, Y1.3
GND: C1.2, C2.2, C3.2, C4.2, C5.2, C6.2, C7.2, C8.2, C9.2, C10.2, C11.2, C12.2, C13.2, C14.2, C15.2, C16.2, C17.2, C18.2, C19.2, C20.2, C21.2, C22.2, C23.2, C24.2, C25.2, C26.2, C27.2, C28.2, C29.2, C30.2, C31.2, C32.2, C33.2, C34.2, C35.2, C36.2, C37.2, C38.2, C39.2, C40.2, C41.2, C42.2, C43.2, C44.2, C45.2, C46.2, C47.2, C48.2, C49.2, C50.1, C51.2, C52.1, C53.2, D1.2, D2.1, D3.1, D4.1, J1.A1, J1.A8, J1.A12, J1.B1, J1.B8, J1.B12, J2.4, J3.7, J3.8, J5.1, R1.2, R3.2, R4.1, R5.1, R10.2, R15.2, R19.2, R20.2, R26.2, R28.2, R33.1, R36.1, R37.1, R38.1, R39.1, R40.1, R41.1, RN5.5, RN5.6, RN5.7, RN5.8, RN6.5, RN6.6, RN6.7, RN6.8, RN7.5, RN7.6, RN7.7, RN7.8, RN8.5, RN8.6, RN8.7, RN8.8, SW1.2, TP3.1, U1.16, U1.20, U1.23, U1.30, U1.34, U1.41, U1.54, U1.78, U2.4, U3.2, U4.4, U5.2, U6.2, U7.4, U7.10, U7.15, U7.21, U7.28, U7.34, U7.39, U7.45, Y1.2, Y1.4
unnamed: C20.1, C48.1, U1.26
unnamed: C22.1, R11.1, R12.1, U3.1
unnamed: C25.1, C27.1, U1.31
unnamed: C28.1, C30.1, U1.35
unnamed: C38.1, C40.1, U1.40
unnamed: D1.1, R29.1
unnamed: D1.3, R30.1
unnamed: D1.4, R31.1
unnamed: D2.2, F1.2, J1.A4, J1.A9, J1.B4, J1.B9
unnamed: J1.A5, R4.2
unnamed: J1.B5, R5.2
unnamed: J1.S1, R1.1
unnamed: J4.1, R32.1
unnamed: L1.2, U1.19
unnamed: L2.2, U3.3
unnamed: R10.1, U1.27
unnamed: R14.2, R15.1, U3.5
unnamed: R21.1, R22.1, R23.1, R24.1, R25.2, R26.1, U5.4
unnamed: RN4.7, RN8.2
unnamed: RN4.8, RN8.1
Vdrive: C44.1, C51.1, C52.2, C53.1, J2.2, J3.1, J3.2, R25.1, R27.1, U5.5, U6.6, U7.7, U7.18
